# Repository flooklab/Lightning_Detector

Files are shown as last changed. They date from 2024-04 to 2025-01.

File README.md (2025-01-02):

# Lightning Detector

Lightning Detector is an experimental open hardware project for early notification about approaching thunderstorm activity.
It is a battery-powered (1x or 2x `CR2032`) device with low power consumption in mind and is based on an Arduino Nano 33 BLE
as microcontroller unit (MCU) and the `AS3935` "Franklin Lightning Sensor" chip by AMS/ScioSense as main detector element.  

For license information please see the [License Information](#user-content-license-information) section at the bottom.  

**! ! ! ! ! WARNING ! ! ! ! !**  
  
**Do _NOT_ actually use Lightning Detector as a serious device to warn you about lightnings or thunderstorms!**  
It might be that lightnings will **NOT** be detected and that you will **NOT** be notified about present or
approaching thunderstorms. You have to assume that the device is inherently **UNSAFE** and does **NOT**
work properly. There is **NO** guarantee for the fitness for any particular purpose whatsoever.  
**UNDER NO CIRCUMSTANCES** should you trust the information provided (or not provided) by the device.
Lightning Detector might **NOT** be tested thoroughly enough and is **NOT** even *intended* to be a reliable detector device.  
Note that being in a thunderstorm (especially without sufficient protection around you (such as a building))
is a very dangerous situation as you might suddenly be struck by lightning, which is potentially **LIFE-THREATENING**.
Generally, you should always try to combine multiple sources of information to assess the current risk of thunderstorms
and lightning strikes. Check the weather forecast and watch the sky. Dark clouds can be an early indicator.
If in doubt (or when there is/are audible thunder or visible lightnings at the latest), please seek shelter!  
  
**! ! ! ! ! WARNING ! ! ! ! !**  
  
See also below *DISCLAIMER AND LIABILITY* [*- OHL-W*](#user-content-disclaimer-and-liability---ohl-w) and
[*- GPL*](#user-content-disclaimer-and-liability---gpl) and [*- OFL*](#user-content-disclaimer-and-liability---ofl)!  
  
The `AS3935` detects lightning strikes indirectly by means of their accompanying electromagnetic radiation,
which is claimed to work up to a maximum distance of 40 kilometers according to its datasheet. For every
lightning that is detected by the `AS3935` the Lightning Detector is going to generate an acoustic notification
(buzzer beep). Additionally, information such as accumulated lightning count and estimated "thunderstorm distance"
etcetera may be shown on a connected display. You may also establish a serial connection via the Arduino USB
connector to read debug information such as detailed data for every lightning and battery voltage etcetera.
A number of internal settings of the `AS3935` can be configured/tweaked via DIP switches in order
to individually optimize detection efficiency and false positive rejection. For a more detailed
overview about the usable features of Lightning Detector please refer to the below sections
[Configuration / Modification](#user-content-configuration--modification) and [Usage](#user-content-usage).  

This project consists of two main components:

1. Hardware design files for a printed circuit board (PCB)
2. Firmware source code for the Arduino MCU

To assemble and use the Lightning Detector the following additional *active* components are required:

## Additional Components

- Arduino Nano 33 BLE (Rev1):  
  See for instance [here](https://store.arduino.cc/products/arduino-nano-33-ble).

- SparkFun Lightning Detector AS3935 (or an equivalent unit containing an AMS/ScioSense `AS3935` chip and appropriate antenna):  
  See for instance [here](https://www.sparkfun.com/products/15441).

- Waveshare 1.54inch e-Paper Display [**optional**, display usage can be configured/disabled, see [below](#user-content-configuration--modification)]:  
  See for instance [here](https://www.waveshare.com/product/1.54inch-e-paper-module.htm).

- SparkFun 16 I/O Expander Breakout SX1509 (or an equivalent unit containing a Semtech `SX1509` chip) [**optional**, required if the above display is used]:  
  See for instance [here](https://www.sparkfun.com/products/13601).

## Hardware Assembly

You should be able to make or order a Lightning Detector PCB using the contents of the [`Hardware/`](Hardware/) directory.
In particular, there are KiCad and also Gerber files, which should enable you to do this.  

To assemble the PCB you should use the parts listed in the bill of materials (BOM) in [`Hardware/BOM/`](Hardware/BOM/).
In [`Hardware/Render_Images/`](Hardware/Render_Images/) there are render images that can be used as a reference for assembly.  

Notes about direct soldering of the Arduino:

- The Arduino is soldered directly to the PCB, unlike the other active components listed in the above
  [Additional Components](#user-content-additional-components) section, which will be later connected via the pin headers on the bottom
  side of the PCB. You could also install pin sockets in place of the Arduino footprint to be able to easily remove/replace the Arduino.
- Components `J1`, `J7` and `R3` must be installed *before* `A1` (the Arduino), unless you choose the pin socket variant mentioned above.
- For reasons of power saving (due to the small coin cell capacity) you should **cut the "3v3" jumper** `SJ4` on the Arduino board.
  This is, of course, also only possible *before* installing the Arduino to the Lightning Detector PCB, so keep this in mind!
  Again, if you choose the pin socket variant for the Arduino, this can be fixed later. Note that with the cut jumper the
  USB connector will not be able to provide power anymore, which is why you will then have to provide power over the
  Lightning Detector PCB before being able to program the Arduino or otherwise use the USB serial connection.

Further notes:

- The bottom side pin headers `J1`, `J2` and `J7` must be soldered with a slight angle with respect to the
  PCB to leave enough space for jumper cables to be connected without interfering with other components' pins.
  It is particularly helpful to limit the length of the Arduino pin ends sticking through to the
  bottom side by deliberately soldering the Arduino at an increased distance to the board.
- The two pin headers `J2` and `J7` (for `I2C`) are meant for powering and controlling the display. If you decide to use
  Lightning Detector without a display (see [Firmware Building](#user-content-firmware-building) below), they can be left out.

### Connecting Periphery

Connecting the "periphery" modules can be simply done via jumper cables.  

The SparkFun AS3935 module must be connected to pin header `J1`. Its pins map to the module pins as follows:  
(`PWR` -> `3V3`), (`SCK` -> `SCK`), (`GND` -> `GND`), (`IRQ` -> `INT`), (`MISO` -> `MISO`), (`MOSI` -> `MOSI`), (`SEL` -> `CS`)  

For reasons of power saving you should disable the power LED on the SparkFun AS3935 module by **cutting the "LED" jumper** `JP5` there.  

If the pre-defined display configuration (i.e. Waveshare 1.54inch e-Paper Display + SparkFun 16 I/O Expander Breakout SX1509)
is going to be used, you can proceed as follows:

- Pin headers `J2` and `J7` should be connected to the power and `I2C` pins of the SparkFun SX1509 module, respectively:  
  (`PWR` -> `3V3`), (`GND` -> `GND`), (`SCL` -> `SCL`), (`SDA` -> `SDA`)
- The I/O pins `#12` through `#15` of the SX1509 module are connected to the e-Paper module like this:  
  (`#12` -> `BUSY`), (`#13` -> `RST`), (`#14` -> `DC`), (`#15` -> `CS`)
- Power pins of the e-Paper module (`VCC` and `GND`) may either be connected to `J2` as well
  (using split jumper cables) or simply to the spare `3V3` and `GND` pins on the SX1509 module.
- The e-Paper module shares the SPI bus with the AS3935 module. Hence two specific pins of `J1`
  must also be connected to the corresponding e-Paper module pins (using split jumper cables):  
  (`SCK` -> `CLK`), (`MOSI` -> `DIN`)

### Example Setup

The final assembly may look similar to this:  

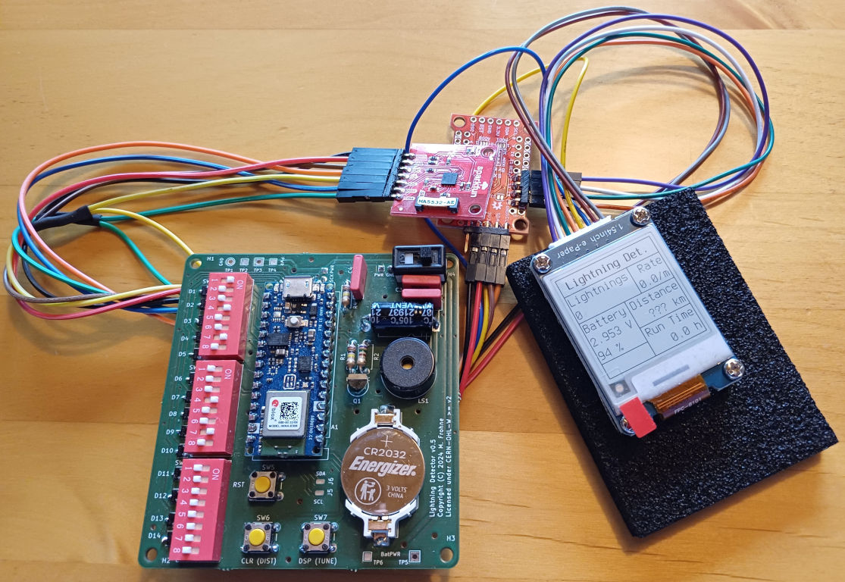
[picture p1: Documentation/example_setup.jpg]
Example setup


#### Case

In [`Hardware/Case/`](Hardware/Case/) there are CAD files for a 3D-printable case that can be
used if all above-mentioned additional periphery modules are attached to the back of the PCB
in a particular layout using the mounting holes and appropriate spacers, as can be seen below:  

<p align="center"><table><tr>
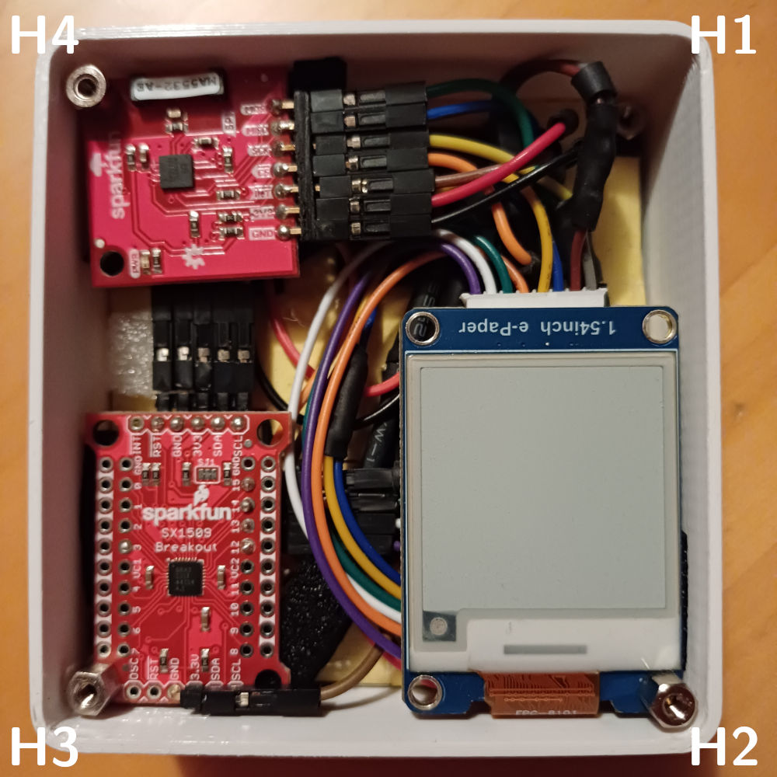
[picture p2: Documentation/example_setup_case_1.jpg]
<td width="33%"></td>
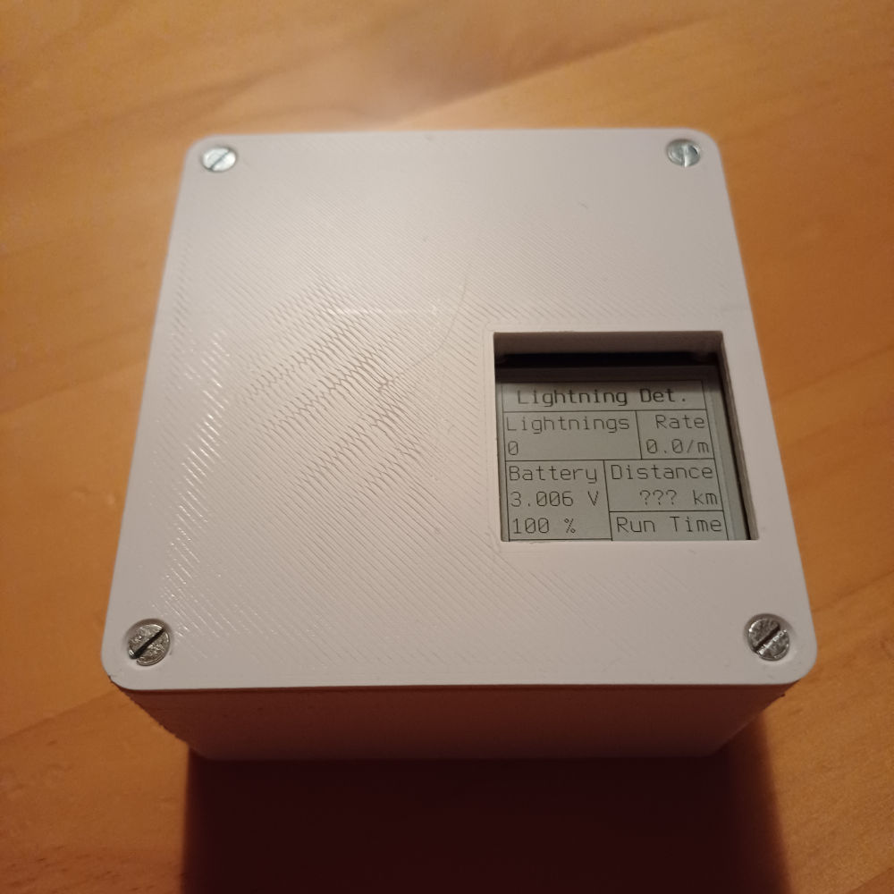
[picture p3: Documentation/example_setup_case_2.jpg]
<td width="33%"></td>
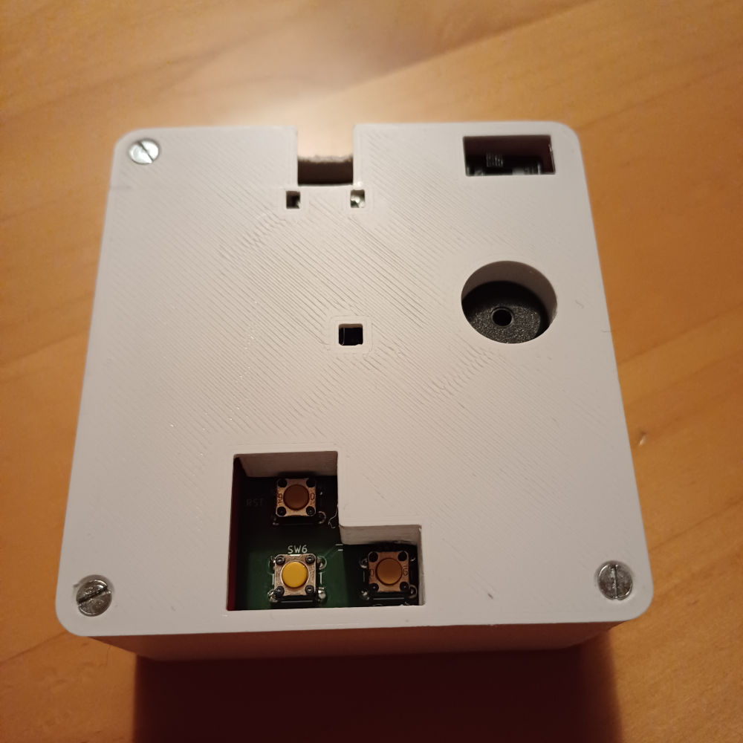
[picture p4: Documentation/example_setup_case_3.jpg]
<td width="33%"></td>
</tr></table></p>

Note that in this configuration the `AS3935` is very close to the rest of the electronics,
which had caused frequent false positive lightning interrupts in my case. This was successfully
suppressed by inserting a grounded sheet of copper foil between the PCB and the attached periphery.

## Firmware Building

Building and uploading the firmware can be accomplished with the [Arduino IDE](https://www.arduino.cc/en/software)
(tested with [Arduino IDE 1.x](https://github.com/arduino/arduino), but should also work with [Arduino IDE 2.x](https://github.com/arduino/arduino-ide)):

- Open the Sketch [`Firmware/lightning_detector/lightning_detector.ino`](Firmware/lightning_detector/lightning_detector.ino)
- If required, make code adjustments to configure things like presence of a display etcetera (see [below](#user-content-configuration--modification))
- Make sure to select the correct board type ("Arduino Nano 33 BLE")
- Connect the Arduino via USB and, if `SJ4` was cut (see [Hardware Assembly](#user-content-hardware-assembly) above), power up the Lightning Detector device
- Compile the sketch and then upload it to the Arduino

Depending on your operating system, your Arduino IDE version and your preference, you might have to make sure
that you additionally have the following software components installed, prior to building the firmware:

- The [Arduino Core for `mbed` MCUs](https://github.com/arduino/ArduinoCore-mbed) (including the [Arduino Core API](https://github.com/arduino/ArduinoCore-api))
- A working [GCC](https://gcc.gnu.org/) toolchain for the `arm-none-eabi` target platform (including [Newlib](https://www.sourceware.org/newlib/))
- A patched version of [BOSSA](https://github.com/arduino/BOSSA/commit/37600d1635f830cc0cdf7c56e586a021272c4e35) from Arduino for uploading the Sketch

Those can be either installed using the Arduino IDE board manager (simply look for "Mbed OS Nano Boards" and/or "Arduino Nano 33 BLE"),
or by yourself using existing packages provided by your operating system distribution or directly from the mentioned sources.

### Configuration / Modification

Before building the firmware you may want to do some code modifications, the most important/interesting of which are listed in the following:

- **Use different SX1509 I/O pins:**  
  If desired, the specific I/O pin numbers of the `SX1509` that are used for the e-Paper module signals `BUSY`, `RST`, `DC` and `CS`
  may be changed in the file [`pins.h`](Firmware/lightning_detector/pins.h) (within the `namespace SX1509Pins`).

- **Disable display usage:**  
  If no display is going to be connected, set the `USE_DISPLAY` macro in [`usedisplay.h`](Firmware/lightning_detector/usedisplay.h) to `USE_DISPLAY_NONE`.

- **Use a different display:**  
  The display part of the firmware is somewhat modular so that it is basically possible to use a completely different display module
  by "simply" writing a dedicated driver class implementation for it, which can of course be modified from the existing display driver
  (see [`display_waveshareepaper154bw_sx1509ioexpander.h`](Firmware/lightning_detector/display_waveshareepaper154bw_sx1509ioexpander.h)
  and [`display_waveshareepaper154bw_sx1509ioexpander.cpp`](Firmware/lightning_detector/display_waveshareepaper154bw_sx1509ioexpander.cpp)).  
  Furthermore, you will need to make the following changes:
  - Add a new macro to [`usedisplay.h`](Firmware/lightning_detector/usedisplay.h) and assign it to `USE_DISPLAY` there.
  - Add the new class header to [`display.h`](Firmware/lightning_detector/display.h) using the previously added macro.
  - Add a matching display declaration in the main [`lightning_detector.ino`](Firmware/lightning_detector/lightning_detector.ino) file (search for `USE_DISPLAY`).

- **General tweaks:**  
  At the top of [`lightning_detector.ino`](Firmware/lightning_detector/lightning_detector.ino), right before the declaration of
  the *interrupt flags*, there are a bunch of constant definitions, which can be adjusted to your liking, such as, for instance:
  - `buzzerFreq`: Buzzer beep frequency
  - `buzzerLightBeepSecs`: Buzzer beep duration for lightning notification
  - `lightRateAvrgMins`: Minimum averaging time to determine current lightning rate
  - `systemMinVoltage`: Largest minimum allowed operating voltage for any system component
  - `systemMaxCurrent`: Maximum system current (e.g. during beep or display update)
  - `systemBatteryCount`: Number of installed coin cells

### Documentation

Firmware code documentation can be generated using [Doxygen](https://github.com/doxygen/doxygen)
(there is a `Doxyfile` in [`Documentation/Firmware/`](Documentation/Firmware/)).

## Usage

### Before Use

- **DIP switch settings:**  

  Make sure to set the DIP switches to the default configuration before use. From left to right (`D1` to `D14`) this is:

  ```
  Register AFE_GB NF_LEV WDTH SREJ TUN_CAP LCO_FDIV MIN_NUM_LIGH
  Value    10010  010    0010 0010 0000    00       00
  ```

  **Note 1:** The default amplifier gain setting `AFE_GB` is recommended for _indoor_ use. For _outdoor_ use they recommend `01110` instead.  
  **Note 2:** The _optimal_ "default" `TUN_CAP` setting is later determined via the antenna tuning procedure (see below).
              The above default is just an arbitrary starting point.  

  The register settings can of course be tweaked as you like. For the meaning/effect of each register please refer to the `AS3935` datasheet.  

- **Antenna tuning:**  

  The AS3935 module antenna needs to be tuned to the resonance frequency of `500 kHz +- 17.5 kHz` before use.
  This can be achieved with the antenna tuning mode (see below).

### Using The Lightning Detector

There are three different "run modes" that can be selected at startup:
- _Normal_: Normal lightning detection mode
- _UnmaskDisturbers_: Same as _Normal_ mode, except for unmasked disturber interrupts and enabled serial connection
- _TuneAntenna_: Antenna tuning mode

The default mode is the _Normal_ mode. Just power up the device to use this mode.  

The _Normal_ mode can be overridden at startup by pressing the `CLR (DIST)` button (_UnmaskDisturbers_) or the `DSP (TUNE)` button (_TuneAntenna_) when/until
the second short buzzer beep is played. There is a first short buzzer beep followed by a `500 ms` delay that enables you to press the buttons in time.

- **_Normal_:**  

  In the _Normal_ mode the main functionality is the lightning notification. Whenever the `AS3935` detects a lightning signal the
  Arduino wakes up from sleep mode (which is used most of the time) via interrupt request and then there is going to be a buzzer
  beep and a short _red_ blip of the RGB LED on the Arduino board. After that the Arduino goes to sleep mode again to save power.  

  Other wake-up reasons (i.e. available functionality) are one of the two push buttons (`CLR (DIST)` or `DSP (TUNE)`) being pressed,
  other `AS3935` IRQ events and a recurring timer timeout (see explanations below). All of the `AS3935` interrupts produce a
  _red_ RGB LED blip, pressed buttons produce a _green_ RGB LED blip and the timer wake-up produces a _blue_ RGB LED blip.  

  Using the lightning interrupts the total number of lightnings is counted and an average lightning rate is calculated.
  Also the estimated storm distance is read for every lightning interrupt and for the dedicated "distance changed" interrupts
  (purely age-based statistics evolution). All of this information (and more) can be displayed on the display on request
  (see below), including, which was the last `AS3935` interrupt. Note, in that regard, that there is also an interrupt
  for too much antenna/amplifier noise. This does not have any direct effect other than the LED blips but can thus
  of course be checked for on the display. Note that the _disturber_ signal interrupts are disabled in this mode.  

  The timer wake-up is used (a) to periodically monitor the battery voltage and (b) to avoid being locked when an `AS3935`
  interrupt is raised while going to sleep as the IRQ signal is not transient but stays high until the interrupt type
  is read. The timer itself is also used to calculate the lightning rate and to accumulate the device's run time.  

  Pressing the `CLR (DIST)` button clears the `AS3935` distance estimation statistics, resets lightning counter
  and lightning rate as well as the latest interrupt type and the latest read lightning "energy" value.  

  Pressing the `DSP (TUNE)` button updates the display. The displayed information is (~ from top-left to bottom-right):
    1. Lightning count
    2. Current lightning rate
    3. Battery state (raw voltage and an estimated charge percentage)
    4. Estimated storm distance from `AS3935` ("???" if reported out of range)
    5. Short status information (from left to right):
        - 'D' if run mode is _UnmaskDisturbers_ (see dedicated section), just ' ' (space) else
        - 'S' if serial connection is enabled (see _UnmaskDisturbers_ mode as well), just ' ' (space) else
        - Latest interrupt type:
          - "" (nothing) for "lightning"
          - "dDst" for "distance changed"
          - "Dist" for "disturber detected" (see _UnmaskDisturbers_ mode)
          - "NOIS" for "too much noise"
          - "INV" for invalid interrupts
    6. Approximate device run time as hours (`xx.x h`) if below 24 hours or as days+hours (`xxxd xxh`) otherwise.

  Note that the reported battery percentage is just an estimate using a look-up table based on some discharge curve. This is already
  inaccurate, although it does take current consumption and internal battery resistance into account. However, those two quantities
  are just approximately known in advance and also the `CR2032` batteries do seem to have somewhat unpredictable, additional voltage
  fluctuations under varying load currents. Therefore please consider the percentage value just as a **very** rough estimate.
  The value seems to get more predictable/reliable, though, when the device has been continuously running for a few days.  

  Also note that the reported "storm distance" value should not necessarily be trusted. This quantity cannot really be _measured_
  using a single sensor at just one place. The value comes directly out of the `AS3935` chip and the datasheet claims that the chip
  can estimate the storm distance by means of a statistical algorithm. There is little explanation of this algorithm, so it might
  actually work but it might as well not work satisfactorily. The value is in any case shown on the display for completeness.  

  If you see the noise interrupt and cannot get rid of it via the `CLR (DIST)` button, refer to the `AS3935` datasheet for how to change the
  register settings to mitigate the noise issue. Note that the configuration is only read from the DIP switches _once_ at startup/reset.  

  The maximum run time of the device is mostly limited by the `AS3935` current consumption. This _should_ be around `350 µA` _or_ `60 µA` for the
  "signal verification mode" _or_ the "listening mode", respectively, according to the datasheet. The sensor should automatically switch to the
  power saving "listening mode" when there is no significant antenna activity, but so far I _could not confirm this by measurements_. Note that
  I made the measurements in a populated area (i.e. picked up noise from surrounding electronics etcetera) and that it might eventually switch
  to "listening mode" when in the back country (which I did _not_ test, though). Adding the much smaller Arduino sleep current (and accounting
  for a higher current during the occasional wake-ups), this means that the Lightning Detector should be able to run for either _almost 6 weeks_
  ("signal verification mode") or _up to 5 months_ ("listening mode") when using two good, parallel `CR2032` batteries (not tested yet either).
  Note, of course, that the achievable run time will be much smaller if you mostly or only use the device during known thunderstorms.  

  The operating voltage is measured approximately every 30 minutes (or every 10 minutes when there is high lightning activity, due to the increased
  current consumption). This only happens when the Arduino wakes up anyway because of one of the mentioned interrupts. If the voltage dropped below
  the point where the minimum operating voltage could not be sustained under the maximum expected current consumption (i.e. below around `2.51 V`),
  then the display is automatically updated one last time and both the buzzer beep and updating the display get disabled to save power. This is also
  acoustically notified using a few seconds long beep sequence (12 beeps). The battery percentage on the display should now read (approximately)
  `0 %`. What remains for the lightning notification are the mentioned RGB LED blips (and serial debug messages for _UnmaskDisturbers_ mode,
  see section below). When the voltage finally drops below the minimum voltage for the `AS3935` chip (`2.4 V`), then the device becomes useless.
  As it cannot switch itself off, it now enters an infinite "sleep loop". This basically disables all functionality, except that now, whenever the
  previously mentioned wake-up timer times out, there will be a 5x blink sequence of the _blue_ RGB LED to remember to switch the device off.

- **_UnmaskDisturbers_:**  

  This mode basically works the same as the _Normal_ mode. The difference is that the `AS3935` now also generates interrupts
  for signals recognized as "disturbers" and that the serial connection will be enabled if a connection is attempted at startup.  

  The disturber interrupts do _not_ generate beeps but can still be recognized by the _red_ RGB LED blips.
  Furthermore it can now be seen on the display if the last `AS3935` interrupt was caused by a disturber.
  If the serial connection is active (see also below), the disturber event is also printed to the serial console.  

  After the second short buzzer beep at startup, if _UnmaskDisturbers_ mode was selected, there is a delay of 5 seconds during which you can attempt
  to connect to the Arduino via a serial console (`9600 Baud`). If this is successful, this will be be used in the following to output a number
  of debug messages, such as `AS3935` events, measured `VDD` voltage etcetera. Please refer to the code for all the possible messages.

- **_TuneAntenna_:**  

  This mode starts with a "buzzer response" test sequence, which can be ignored for the first procedure (see below)
  but can be helpful for the second "acoustic matching" procedure and is hence further explained there (see further below).  

  Whenever the `DSP (TUNE)` button gets pressed the current DIP switch configuration is read and applied to the `AS3935`.
  This can be used to adjust the `TUN_CAP` register setting until the resonance frequency matches the `500 kHz` (remember
  the uncertainty window of `+- 3.5%`, respectively `+- 17.5 kHz`). There are two possibilities for the tuning procedure:

  - Tuning with an oscilloscope or similar devices:  
    Set `LCO_FDIV` to `00` or an appropriate higher value given the bandwidth limit of your measurement device.
    The `00` setting yields a digital `~ 500/16 kHz = 31.25 kHz` signal at the IRQ pin of the AS3935 module,
    which can then be measured and matched using the `TUN_CAP` register. `LCO_FDIV` equal to `01` divides
    by 32, `10` divides by 64 and `11` divides by 128 (`~ 3.9 kHz`).

  - Tuning using the buzzer and acoustic frequency matching:  
    If no such measurement device is available, set `LCO_FDIV` to `11` (or `10`). This will reproduce the digital
    resonance signal of the IRQ pin on the buzzer output such that you can acoustically match the audible frequency
    to `~ 500/128 kHz` (or `~ 500/64 kHz`) using an instrument tuner or by generating a beat signal versus the target
    frequency. The sound always plays as long as the `DSP (TUNE)` button is being pressed. Note that you should
    listen to the "buzzer response" test sequence played in the beginning to assess the suitability of the used
    buzzer for the acoustic matching procedure. Depending on the buzzer model (avoid its resonance frequency)
    and the chosen frequency (`LCO_FDIV`) you might not be able to resolve different frequencies sufficiently
    well to be able to properly tune the antenna. The sequence plays 13 beeps with frequencies around the
    divided target frequency, all separated by steps of 10 cents. You should be able to resolve at least
    around 3 of those 13 frequencies. The test uses the frequency according to the `LCO_FDIV`
    setting at startup. Start with `11` and if that does not work out use `10` instead.

## Known Issues

- Sometimes the Arduino appears to take rather long to wake up from sleep mode. When you wake it up by pressing
  one of the push buttons, this _can_ result in it getting stuck due to the debouncing (recognizable by the
  _green_ RGB LED being continuously on). You just need to press the button again to resolve this.
- Apparently, as already mentioned in the [Case](#user-content-case) section, the `AS3935`
  raises false positive lightning interrupts when it gets too close to the main PCB.
  Hence you might need to add additional shielding, depending on your setup.

## License Information

Copyright (C) 2024–2025 M. Frohne  

Lightning Detector is licensed under the "*CERN Open Hardware Licence, Version 2 - Weakly Reciprocal*" or (at your option) any later version.  
(please refer to the file [`LICENSE.OHL-W`](LICENSE.OHL-W))  

This does NOT apply to the firmware code that is found in the [`Firmware/`](Firmware/) directory, which is instead
licensed under the "*GNU General Public License, Version 3*" or (at your option) any later version.  
(please refer to the file [`LICENSE.GPL`](LICENSE.GPL))  

Note also that the firmware files in the directory [`Firmware/lightning_detector/fonts/`](Firmware/lightning_detector/fonts/) embed a subset
of the Terminus Font and are hence additionally licensed under the "*SIL Open Font License, Version 1.1*", with Reserved Font Name "Terminus Font".  
(please refer to the file [`LICENSE.OFL`](LICENSE.OFL))

### DISCLAIMER AND LIABILITY - OHL-W

- DISCLAIMER OF WARRANTY -- The Covered Source and any Products
  are provided 'as is' and any express or implied warranties,
  including, but not limited to, implied warranties of
  merchantability, of satisfactory quality, non-infringement of
  third party rights, and fitness for a particular purpose or use
  are disclaimed in respect of any Source or Product to the
  maximum extent permitted by law. The Licensor makes no
  representation that any Source or Product does not or will not
  infringe any patent, copyright, trade secret or other
  proprietary right. The entire risk as to the use, quality, and
  performance of any Source or Product shall be with You and not
  the Licensor. This disclaimer of warranty is an essential part
  of this Licence and a condition for the grant of any rights
  granted under this Licence.

- EXCLUSION AND LIMITATION OF LIABILITY -- The Licensor shall, to
  the maximum extent permitted by law, have no liability for
  direct, indirect, special, incidental, consequential, exemplary,
  punitive or other damages of any character including, without
  limitation, procurement of substitute goods or services, loss of
  use, data or profits, or business interruption, however caused
  and on any theory of contract, warranty, tort (including
  negligence), product liability or otherwise, arising in any way
  in relation to the Covered Source, modified Covered Source
  and/or the Making or Conveyance of a Product, even if advised of
  the possibility of such damages, and You shall hold the
  Licensor(s) free and harmless from any liability, costs,
  damages, fees and expenses, including claims by third parties,
  in relation to such use.

See the CERN Open Hardware Licence for more details. 

### DISCLAIMER AND LIABILITY - GPL

Lightning Detector's firmware is distributed in the hope that it
will be useful, but WITHOUT ANY WARRANTY; without even the implied
warranty of MERCHANTABILITY or FITNESS FOR A PARTICULAR PURPOSE.  

See the GNU General Public License for more details.

### DISCLAIMER AND LIABILITY - OFL

THE FONT SOFTWARE IS PROVIDED "AS IS", WITHOUT WARRANTY OF ANY KIND,
EXPRESS OR IMPLIED, INCLUDING BUT NOT LIMITED TO ANY WARRANTIES OF
MERCHANTABILITY, FITNESS FOR A PARTICULAR PURPOSE AND NONINFRINGEMENT
OF COPYRIGHT, PATENT, TRADEMARK, OR OTHER RIGHT. IN NO EVENT SHALL THE
COPYRIGHT HOLDER BE LIABLE FOR ANY CLAIM, DAMAGES OR OTHER LIABILITY,
INCLUDING ANY GENERAL, SPECIAL, INDIRECT, INCIDENTAL, OR CONSEQUENTIAL
DAMAGES, WHETHER IN AN ACTION OF CONTRACT, TORT OR OTHERWISE, ARISING
FROM, OUT OF THE USE OR INABILITY TO USE THE FONT SOFTWARE OR FROM
OTHER DEALINGS IN THE FONT SOFTWARE.  

See the SIL Open Font License for more details.

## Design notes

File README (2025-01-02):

Lightning Detector, an experimental open hardware project for early notification about approaching thunderstorm activity.
Copyright (C) 2024–2025 M. Frohne

Lightning Detector is licensed under the "CERN Open Hardware Licence, Version 2 - Weakly Reciprocal" or (at your option) any later version.
(please refer to the file 'LICENSE.OHL-W')

This does NOT apply to the firmware code that is found in the 'Firmware/' directory, which is instead
licensed under the "GNU General Public License, Version 3" or (at your option) any later version.
(please refer to the file 'LICENSE.GPL')

Note also that the firmware files in the directory 'Firmware/lightning_detector/fonts/' embed a subset of the Terminus Font
and are hence additionally licensed under the "SIL Open Font License, Version 1.1", with Reserved Font Name "Terminus Font".
(please refer to the file 'LICENSE.OFL')

###########################################################################################################################################

! ! ! ! ! WARNING ! ! ! ! !

Do NOT actually use Lightning Detector as a serious device to warn you about lightnings or thunderstorms!
It might be that lightnings will NOT be detected and that you will NOT be notified about present or
approaching thunderstorms. You have to assume that the device is inherently UNSAFE and does NOT
work properly. There is NO guarantee for the fitness for any particular purpose whatsoever.
UNDER NO CIRCUMSTANCES should you trust the information provided (or not provided) by the device.
Lightning Detector might NOT be tested thoroughly enough and is NOT even intended to be a reliable detector device.
Note that being in a thunderstorm (especially without sufficient protection around you (such as a building))
is a very dangerous situation as you might suddenly be struck by lightning, which is potentially LIFE-THREATENING.
Generally, you should always try to combine multiple sources of information to assess the current risk of thunderstorms
and lightning strikes. Check the weather forecast and watch the sky. Dark clouds can be an early indicator.
If in doubt (or when there is/are audible thunder or visible lightnings at the latest), please seek shelter!

! ! ! ! ! WARNING ! ! ! ! !

###########################################################################################################################################

For more information please see the file 'README.md'.

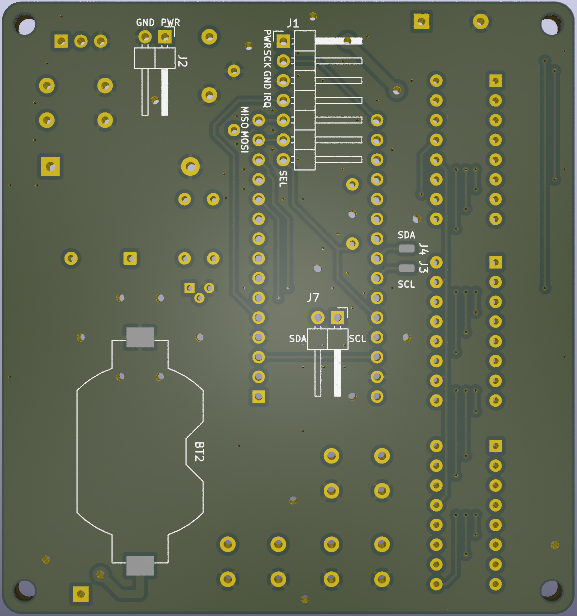
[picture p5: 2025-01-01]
Hardware/Render_Images/2_bare_pcb_back.png

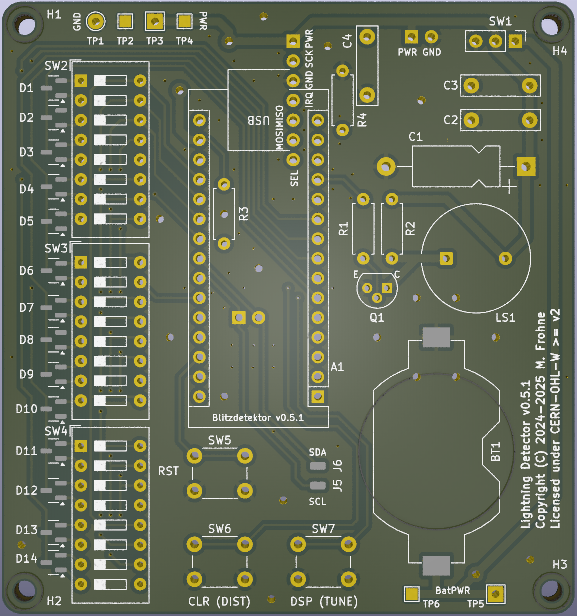
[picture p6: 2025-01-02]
Hardware/Render_Images/1_bare_pcb_front.png

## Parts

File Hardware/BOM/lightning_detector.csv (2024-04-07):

ID | Reference | Footprint | Quantity | Description | Value
1 | SW5,SW6,SW7 | SW_PUSH_6mm | 3 | SW_PUSH_6mm
2 | D1,D2,D3,D4,D5,D6,D7,D8,D9,D10,D11,D12,D13,D14 | SOT-23 | 14 | Schottky Diode Dual Common Anode
3 | SW2,SW3,SW4 | SW_DIP_SPSTx08_Slide_9.78x22.5mm_W7.62mm_P2.54mm | 3 | SW_DIP_SPSTx08_Slide_9.78x22.5mm_W7.62mm_P2.54mm
4 | C2,C3,C4 | C_Rect_L10.0mm_W2.5mm_P7.50mm_MKS4 | 3 | C_Rect_L10.0mm_W2.5mm_P7.50mm_MKS4 | 100n
5 | LS1 | Indicator_PUI_AI-1440-TWT-24V-2-R | 1 | Piezoelectric Buzzer, f_R ~ O(1 kHz)
6 | Q1 | TO-92 | 1 | BC547C
7 | R1,R3,R4 | R_Axial_DIN0207_L6.3mm_D2.5mm_P7.62mm_Horizontal | 3 | R_Axial_DIN0207_L6.3mm_D2.5mm_P7.62mm_Horizontal | 100k
8 | R2 | R_Axial_DIN0207_L6.3mm_D2.5mm_P7.62mm_Horizontal | 1 | R_Axial_DIN0207_L6.3mm_D2.5mm_P7.62mm_Horizontal | 750
9 | C1 | CP_Axial_L11.0mm_D5.0mm_P18.00mm_Horizontal | 1 | CP_Axial_L11.0mm_D5.0mm_P18.00mm_Horizontal | 220u
10 | SW1 | PinHeader_1x03_P2.54mm_Vertical | 1 | SW_SPDT_P2.54mm
11 | A1 | Arduino_Nano | 1 | Arduino Nano 33 BLE Rev1
12 | BT1,BT2 | BatteryHolder_Keystone_1058_1x2032 | 2 | BatteryHolder_Keystone_1058_1x2032
13 | J1 | PinHeader_1x07_P2.54mm_Horizontal | 1 | PinHeader_1x07_P2.54mm_Horizontal
14 | J2,J7 | PinHeader_1x02_P2.54mm_Horizontal | 2 | PinHeader_1x02_P2.54mm_Horizontal

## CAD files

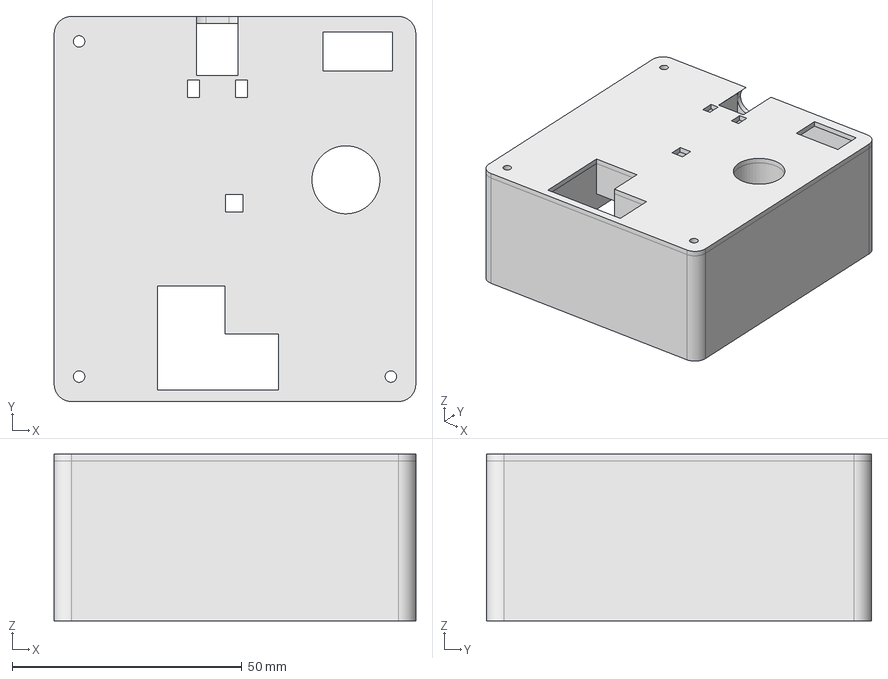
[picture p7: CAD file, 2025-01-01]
Hardware/Case/lightning_detector_case_top.step
78.7 x 83.7 x 36.3 mm

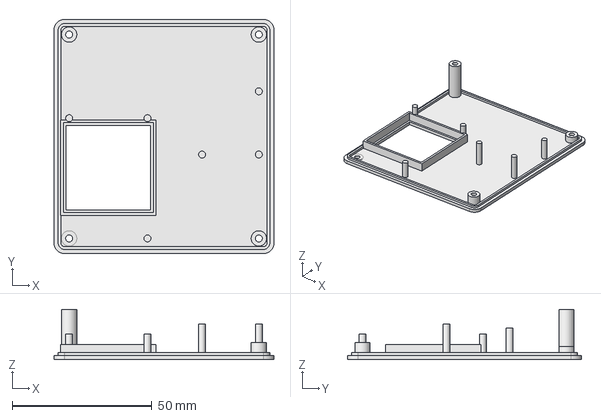
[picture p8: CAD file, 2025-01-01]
Hardware/Case/lightning_detector_case_bottom.step
78.7 x 83.7 x 17.9 mm

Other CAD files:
Hardware/Case/lightning_detector_case_bottom.stl
Hardware/Case/lightning_detector_case_top.stl

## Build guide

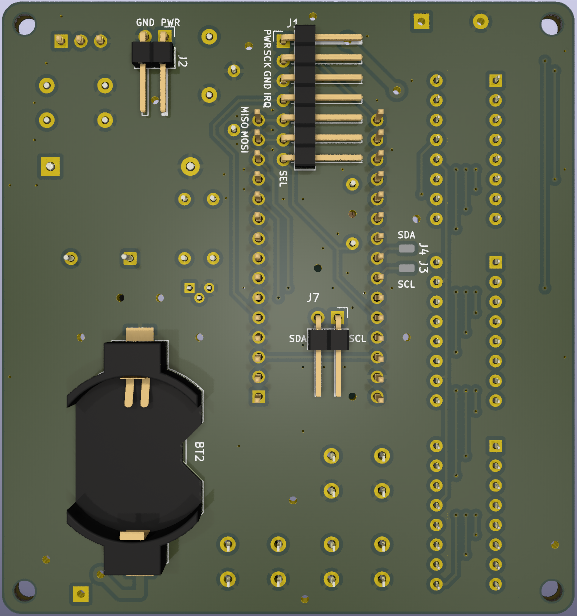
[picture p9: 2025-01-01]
Hardware/Render_Images/4_assembled_pcb_back.png

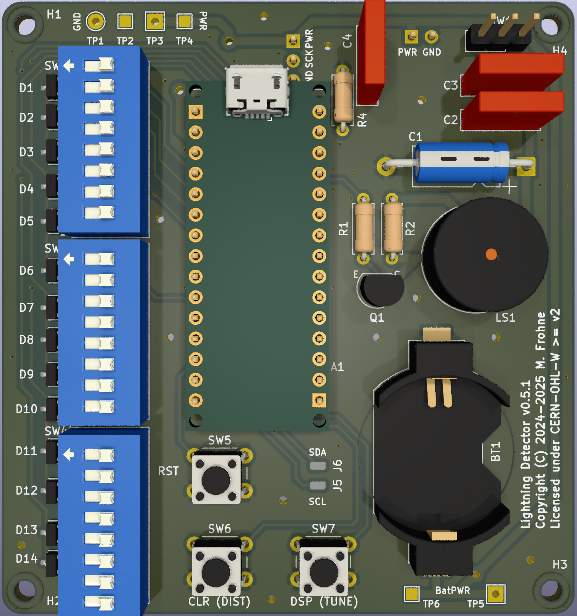
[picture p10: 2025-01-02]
Hardware/Render_Images/3_assembled_pcb_front.png

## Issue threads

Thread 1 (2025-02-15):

AS3935 Stroke integration threshold does not seem to work.

rpbgit, 2025-02-15:
Have 3935 running fine on SPI bus.  And most everything seems like its working well.

I am now tuning some parameters and it appears the Strike Theshold does not seem to work.

i have a lightning simulator that indeed generates lightning strokes as expected.  however, no matter what i set the strike threshold register bits to (values of 0x00-0x03), the first strike causes the interrupt request to be asserted to the micro.

i would have expected that the INTR line would be negated until the threshold count is exceeded.

Reading the INT source register (ISR) negates the INTR pin as expected. I am waiting 2ms from INTR recognition to reading of the ISR as spec mandates.  is clearing of the integration stats require in the ISR?   manually doing a clear statistics does not change the bahavior.

i have the Disturber mask set to prevent INTR from that source and the noise floor is set so that no noise events are generated.   Yet still, the first strike created by my strike generator board results in the INTR pin being asserted.

why is this not working ?   have i mis-interpreted the spec documents?

flooklab, 2025-03-04:
Hi, I cannot really help you with this. If you are talking about the `MIN_NUM_LIGH` register, maybe your "lightning simulator" is just too simple and does not generate a proper signature for a single lightning, maybe there's an error in your register writing, could be a lot of things...

I am closing this issue anyway because it does not seem to refer to this particular project.

Closed 2025-03-04.

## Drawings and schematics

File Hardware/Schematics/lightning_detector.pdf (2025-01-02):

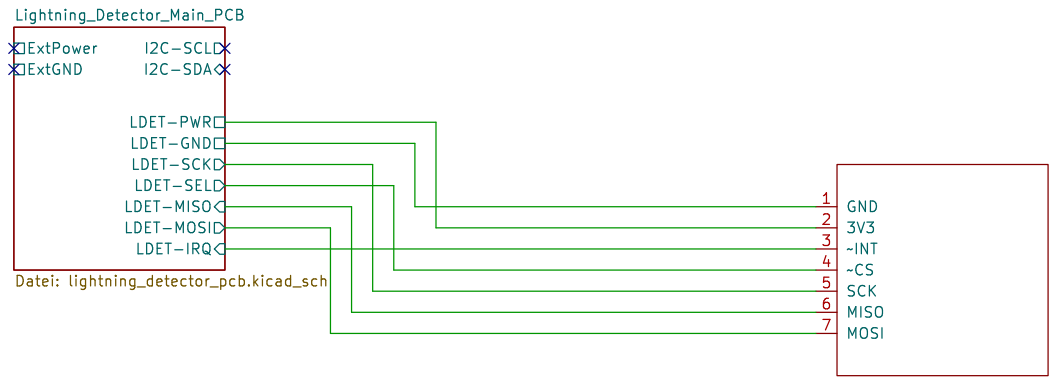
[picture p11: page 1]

LDET-PWR
LDET-GND
LDET-SCK
LDET-SEL
LDET-MISO
LDET-MOSI LDET-IRQ

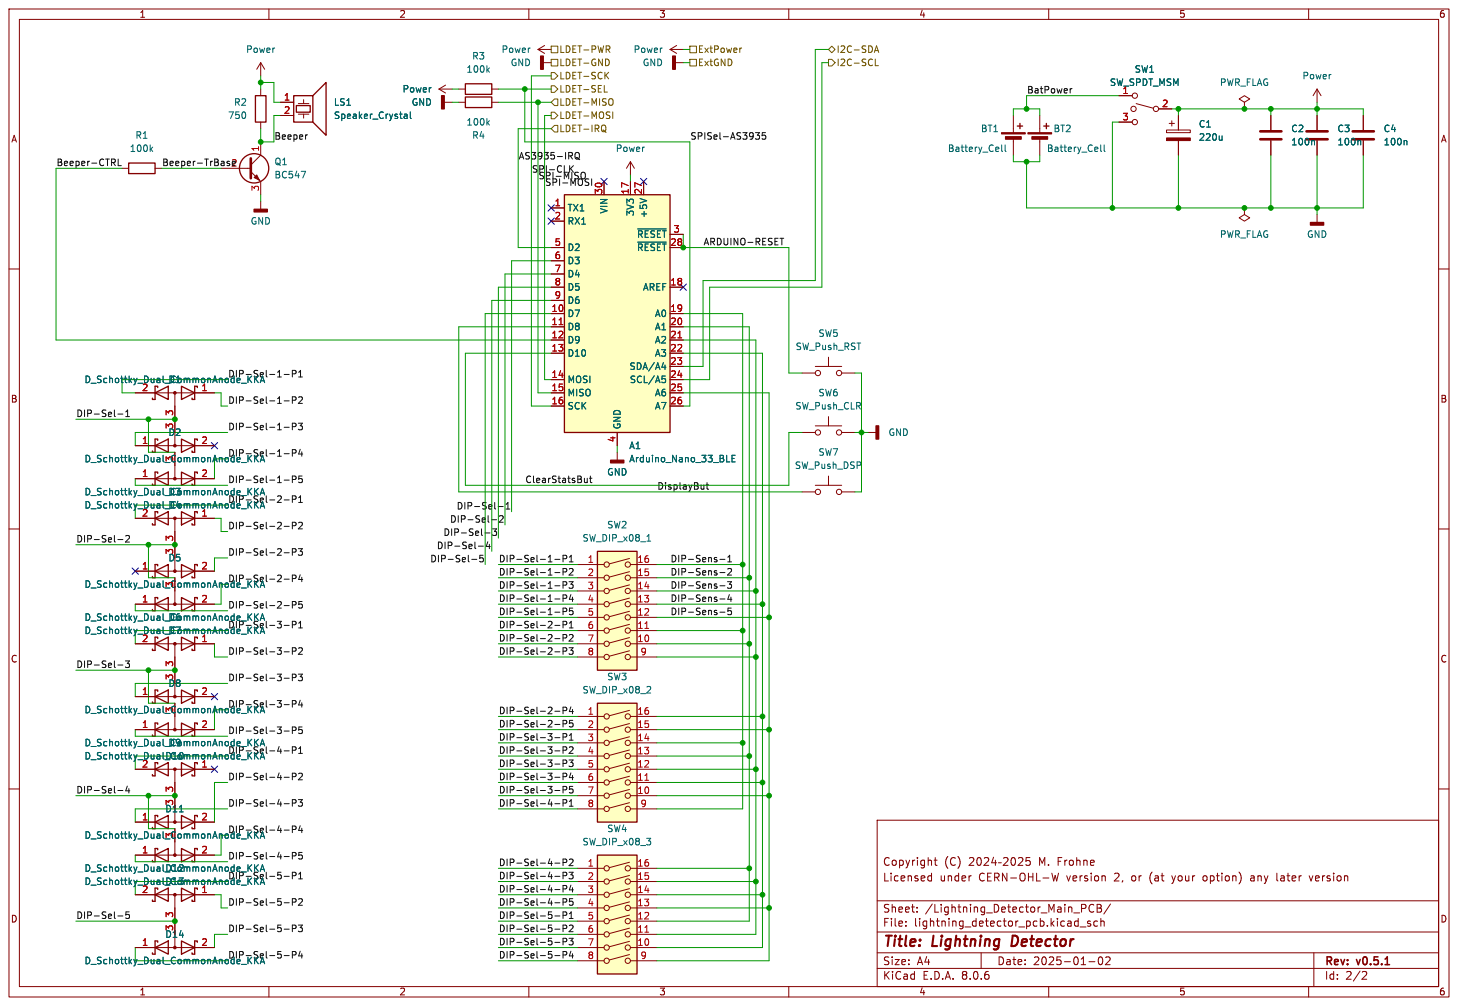
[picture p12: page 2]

3 GND
DIP-Sel-2 DIP-Sel-5

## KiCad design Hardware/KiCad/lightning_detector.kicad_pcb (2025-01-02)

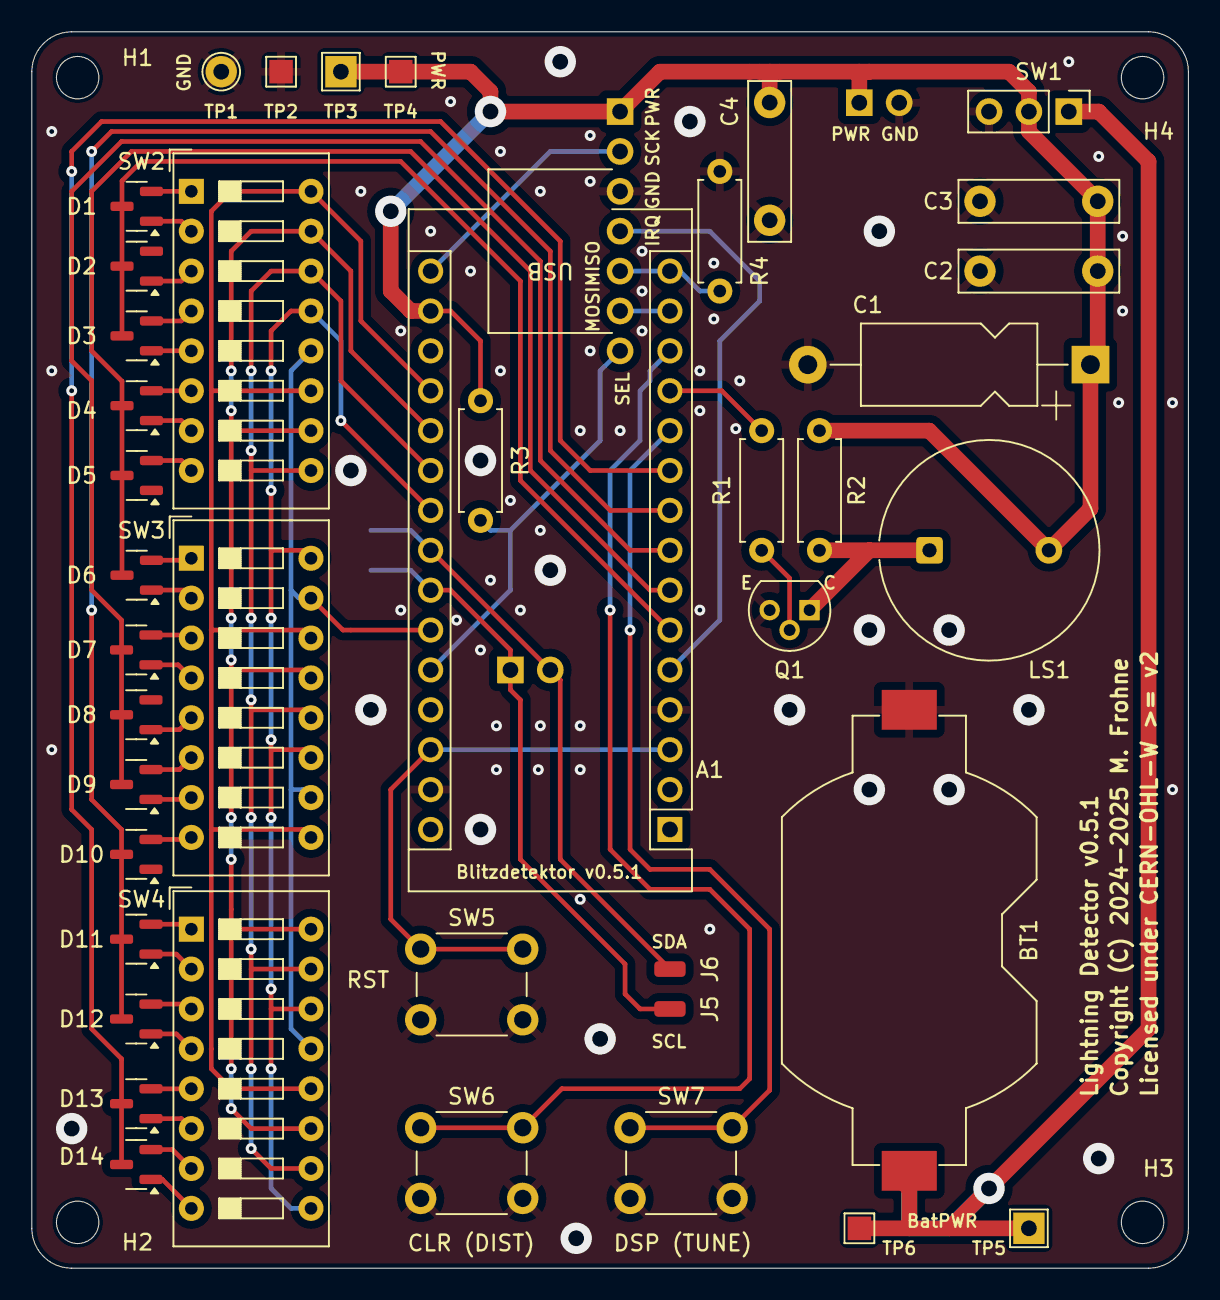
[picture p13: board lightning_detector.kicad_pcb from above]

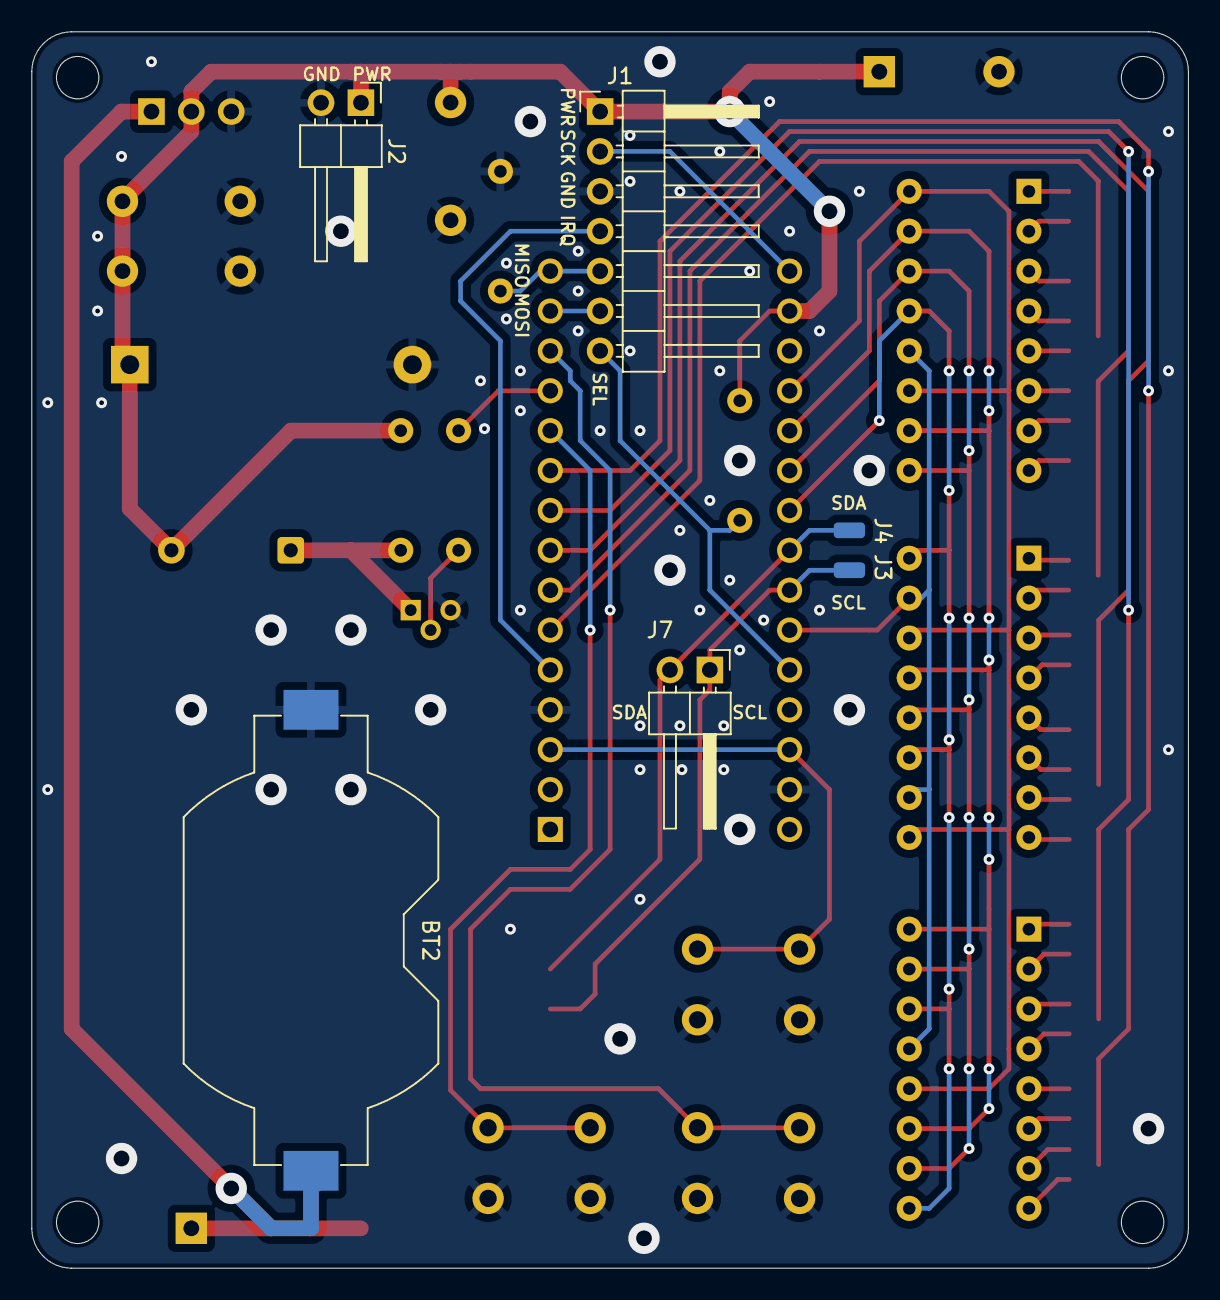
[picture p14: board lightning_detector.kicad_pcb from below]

Board: 2 copper layers, 73.7 x 78.7 mm, 51 parts (6 on the bottom side), 50 nets.

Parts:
A1: Arduino_Nano
BT1, BT2: BatteryHolder_Keystone_1058_1x2032
C1: CP_Axial_L11.0mm_D5.0mm_P18.00mm_Horizontal
C2, C3, C4: C_Rect_L10.0mm_W2.5mm_P7.50mm_MKS4
D1, D2, D3, D4, D5, D6, D7, D8, D9, D10, D11, D12, D13, D14: SOT-23
H1, H2, H3, H4: MountingHole_2.7mm_M2.5_DIN965
J1: PinHeader_1x07_P2.54mm_Horizontal
J2, J7: PinHeader_1x02_P2.54mm_Horizontal
J3, J4, J5, J6: SolderWirePad_1x01_SMD_1x2mm
LS1: Indicator_PUI_AI-1440-TWT-24V-2-R
Q1: TO-92
R1, R2, R3, R4: R_Axial_DIN0207_L6.3mm_D2.5mm_P7.62mm_Horizontal
SW1: PinHeader_1x03_P2.54mm_Vertical
SW2, SW3, SW4: SW_DIP_SPSTx08_Slide_9.78x22.5mm_W7.62mm_P2.54mm
SW5, SW6, SW7: SW_PUSH_6mm
TP1: TestPoint_THTPad_D2.0mm_Drill1.0mm
TP2, TP4, TP6: TestPoint_Pad_1.5x1.5mm
TP3, TP5: TestPoint_THTPad_2.0x2.0mm_Drill1.0mm

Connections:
ARDUINO-RESET: A1.3, A1.28, SW5.1
AS3935-IRQ: A1.5, J1.4
BatPower: BT1.1, BT2.1, SW1.1, TP5.1, TP6.1
Beeper: LS1.1, Q1.1, R2.2
Beeper-CTRL: A1.12, R1.1
Beeper-TrBase: Q1.2, R1.2
ClearStatsBut: A1.13, SW6.1
DIP-Sel-1: A1.6, D1.3, D2.3, D3.3
DIP-Sel-1-P1: D1.2, SW2.1
DIP-Sel-1-P2: D1.1, SW2.2
DIP-Sel-1-P3: D2.1, SW2.3
DIP-Sel-1-P4: D3.2, SW2.4
DIP-Sel-1-P5: D3.1, SW2.5
DIP-Sel-2: A1.7, D4.3, D5.3, D6.3
DIP-Sel-2-P1: D4.2, SW2.6
DIP-Sel-2-P2: D4.1, SW2.7
DIP-Sel-2-P3: D5.2, SW2.8
DIP-Sel-2-P4: D6.2, SW3.1
DIP-Sel-2-P5: D6.1, SW3.2
DIP-Sel-3: A1.8, D7.3, D8.3, D9.3
DIP-Sel-3-P1: D7.2, SW3.3
DIP-Sel-3-P2: D7.1, SW3.4
DIP-Sel-3-P3: D8.1, SW3.5
DIP-Sel-3-P4: D9.2, SW3.6
DIP-Sel-3-P5: D9.1, SW3.7
DIP-Sel-4: A1.9, D10.3, D11.3, D12.3
DIP-Sel-4-P1: D10.2, SW3.8
DIP-Sel-4-P2: D11.2, SW4.1
DIP-Sel-4-P3: D11.1, SW4.2
DIP-Sel-4-P4: D12.2, SW4.3
DIP-Sel-4-P5: D12.1, SW4.4
DIP-Sel-5: A1.10, D13.3, D14.3
DIP-Sel-5-P1: D13.2, SW4.5
DIP-Sel-5-P2: D13.1, SW4.6
DIP-Sel-5-P3: D14.2, SW4.7
DIP-Sel-5-P4: D14.1, SW4.8
DIP-Sens-1: A1.19, SW2.11, SW2.16, SW3.9, SW3.14, SW4.12
DIP-Sens-2: A1.20, SW2.10, SW2.15, SW3.13, SW4.11, SW4.16
DIP-Sens-3: A1.21, SW2.9, SW2.14, SW3.12, SW4.10, SW4.15
DIP-Sens-4: A1.22, SW2.13, SW3.11, SW3.16, SW4.9, SW4.14
DIP-Sens-5: A1.25, SW2.12, SW3.10, SW3.15, SW4.13
DisplayBut: A1.11, SW7.1
GND: A1.4, A1.29, BT1.2, BT2.2, C1.2, C2.1, C3.1, C4.1, J1.3, J2.2, Q1.3, R4.2, SW1.3, SW5.2, SW6.2, SW7.2, TP1.1, TP2.1
I2C-SCL: A1.24, J3.1, J5.1, J7.1
I2C-SDA: A1.23, J4.1, J6.1, J7.2
Power: A1.17, C1.1, C2.2, C3.2, C4.2, J1.1, J2.1, LS1.2, R2.1, R3.2, SW1.2, TP3.1, TP4.1
SPI-CLK: A1.16, J1.2
SPI-MISO: A1.15, J1.5, R4.1
SPI-MOSI: A1.14, J1.6
SPISel-AS3935: A1.26, J1.7, R3.1

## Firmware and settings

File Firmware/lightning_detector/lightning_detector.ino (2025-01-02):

/*
////////////////////////////////////////////////////////////////////////////////////
//
//  This file is part of the firmware of Lightning Detector, an experimental open
//  hardware project for early notification about approaching thunderstorm activity.
//  Copyright (C) 2024–2025 M. Frohne
//
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
////////////////////////////////////////////////////////////////////////////////////
*/

#include "as3935.h"
#include "auxil.h"
#include "buzzer.h"
#include "configuration.h"
#include "display.h"
#include "muxeddipswitch.h"
#include "pins.h"
#include "pushbutton.h"
#include "timercallback.h"
#include "vddmeasurement.h"

#include <USB/PluggableUSBSerial.h>

#include <nrf_nvic.h>
#include <nrf_soc.h>

#include <array>

//Function  declarations

void setupPowerSave();

void readConfiguration();

void tuneAntenna();

void detectLightnings();
bool processInterruptAS3935();

void isrAS3935();
void isrButtonClr();
void isrButtonDsp();
void isrWakeTimer();

//int main();
//void setup();
//void loop();

//Constants

constexpr size_t pushButtonBounceTime = 20;     //Debounce time for used push buttons in milliseconds

constexpr float buzzerFreq = 1000;              //Buzzer beep frequency in Hz
constexpr float buzzerDutyCycle = 0.1;          //Buzzer signal duty cycle

constexpr float buzzerLightBeepSecs = 0.2;      //Buzzer beep duration for lightning notification in seconds

constexpr size_t wakeTimerIntervalSecs = 120;   //Seconds of inactivity before forced wake-up via RTC (prevent missed AS3935 IRQ, etc.)

constexpr size_t vddMeasIntervalMins = 30;      //Scheduled interval between VDD measurements in minutes
constexpr size_t vddMeasSmallIntervalMins = 10; //Smaller VDD measurement interval in minutes for high lightning activity
constexpr float vddMeasLightRateThr = 2.;       //Number of lightnings per minute to switch to smaller measurement interval

constexpr size_t lightRateAvrgMins = 5;     //Minimum ('minimum' due to sleep) averaging time to determine current lightning activity/rate

constexpr float as3935MinVoltage = 2.4;     //Minimum allowed operating voltage for the AS3935 sensor chip in Volt
constexpr float systemMinVoltage = 2.4;     //Largest minimum allowed operating voltage for any system component in Volt
constexpr float systemIdleCurrent = 0.0041; //System current during VDD measurement (while awake and idle otherwise) in Ampere
constexpr float systemMaxCurrent = 0.0081;  //Maximum system current (e.g. during beep or display update) in Ampere
constexpr float batteryOCVoltage0 = 3.0;    //Open-circuit voltage of a nearly fresh coin cell (i.e. ~ nominal voltage) in Volt
constexpr float batteryIntResEOL = 55.0;    //Internal resistance of single coin cell around end of life (~systemMinVoltage) in Ohm
constexpr uint8_t systemBatteryCount = 2;   //Number of installed coin cells

//Minimum allowed voltage for VDD measurement from idle running system
constexpr float lowBatteryThrVoltage = systemMinVoltage + (batteryIntResEOL / systemBatteryCount) * (systemMaxCurrent - systemIdleCurrent);

//Interrupt flags

volatile bool irqWake = false;
volatile bool irqWakeAS3935 = false;
volatile bool irqWakeClr = false;
volatile bool irqWakeDsp = false;
volatile bool irqWakeTimer = false;

//External symbols

extern "C" { extern bool _us_ticker_initialized; }
const bool& timer1Used = _us_ticker_initialized;    //Determines if TIMER1 is used by mbed (see <mbed_wait_api.h>)

//Devices

Buzzer buzzer(Pins::Buzzer, buzzerFreq, buzzerDutyCycle);

PushButton buttonCLR(Pins::PushButtonClr, true, pushButtonBounceTime);
PushButton buttonDSP(Pins::PushButtonDsp, true, pushButtonBounceTime);

MuxedDIPSwitch<5, 5> dip({Pins::DIPSel1, Pins::DIPSel2, Pins::DIPSel3, Pins::DIPSel4, Pins::DIPSel5},
                         {Pins::DIPSens1, Pins::DIPSens2, Pins::DIPSens3, Pins::DIPSens4, Pins::DIPSens5});

AS3935 lDet(Pins::SPI_CS, Pins::IRQ);

#if USE_DISPLAY == USE_DISPLAY_WAVESHAREEPAPER154BW_SX1509IOEXPANDER
    constexpr uint8_t sx1509Addr = 0x3E;
    Display display(sx1509Addr, SX1509Pins::Display_CS, SX1509Pins::Display_DC, SX1509Pins::Display_RST, SX1509Pins::Display_BUSY);
#else
    Display display;
#endif

//"Virtual devices" (using internal periphery)

TimerCallback wakeTimer(8*wakeTimerIntervalSecs, &isrWakeTimer);    //Periodic wake-up timer (binds RTC interrupt)

//Other globals

Configuration config;

using Auxil::RunMode;
RunMode runMode = RunMode::Normal;

bool serialEnabled = false;

AS3935::InterruptType lDetLastInterrupt = AS3935::InterruptType::Lightning; //Last reported interrupt type from AS3935
uint32_t lDetLastEnergy = 0;                                                //Last reported lightning energy from AS3935 (raw value)
uint8_t lDetStormDist = AS3935::stormDistanceOutOfRange;                    //Last reported thunderstorm distance from AS3935 in km

//Function definitions

/*!
 * \brief Configure some power save settings.
 */
void setupPowerSave()
{
    //Turn off power LED
    digitalWrite(Pins::LED_Power, LOW);

    //Disable IMU
    digitalWrite(PIN_ENABLE_SENSORS_3V3, LOW);
    digitalWrite(PIN_ENABLE_I2C_PULLUP, LOW);

    //Configure pull-down for unused RX/TX pins
    pinMode(0, INPUT_PULLDOWN);
    pinMode(1, INPUT_PULLDOWN);

    //Disable UART

    NRF_UARTE0->TASKS_STOPTX = 1;
    NRF_UARTE0->TASKS_STOPRX = 1;
    NRF_UARTE0->ENABLE = 0;

    NRF_UARTE1->TASKS_STOPTX = 1;
    NRF_UARTE1->TASKS_STOPRX = 1;
    NRF_UARTE1->ENABLE = 0;

    NRF_UART0->TASKS_STOPTX = 1;
    NRF_UART0->TASKS_STOPRX = 1;
    NRF_UART0->ENABLE = 0;

    //Disable unused I2C peripheral(s)
    if (!useDisplay)
        NRF_TWI0->ENABLE = 0;
    NRF_TWI1->ENABLE = 0;

    //Disable two unused SPI peripherals
    NRF_SPI0->ENABLE = 0;
    NRF_SPI1->ENABLE = 0;

    //Ensure system is in low power mode
    NRF_POWER->TASKS_LOWPWR = 1;
}

/*!
 * \brief Read the DIP switch configuration bits for setting the AS3935 registers.
 */
void readConfiguration()
{
    std::array<bool, 25> conf25 = dip.readAllBits();
    std::array<bool, 24> conf;

    for (size_t i = 0; i < 24; ++i)
        conf[i] = conf25[i];

    config.load(conf);
}

/*!
 * \brief Perform manual AS3935 antenna tuning (endless loop).
 */
void tuneAntenna()
{
    while (true)
    {
        buttonDSP.waitPressed();

        readConfiguration();

        lDet.writeConfiguration(config);

        uint8_t lcoFDIV = config.getRegister(Configuration::RegIdent::LCO_FDIV);

        //If divided frequency is in audible range, output corresponding sound using buzzer; otherwise just wait for button release
        if (lcoFDIV == 0b11 || lcoFDIV == 0b10)
        {
            size_t tBuzzerOnDelay;
            if (lcoFDIV == 0b11)
                tBuzzerOnDelay = static_cast<size_t>(1000000./3906.25*buzzerDutyCycle);
            else
                tBuzzerOnDelay = static_cast<size_t>(1000000./7812.50*buzzerDutyCycle);

            while (buttonDSP.pressed())
            {
                while (!lDet.irqHigh())
                    ;

                buzzer.switchOutputOn();

                delayMicroseconds(tBuzzerOnDelay);  //Use normal beep duty cycle to improve sound

                buzzer.switchOutputOff();

                while (lDet.irqHigh())
                    ;
            }
        }
        buttonDSP.waitReleased();
    }
}

/*!
 * \brief Perform the lightning detection (endless loop).
 */
void detectLightnings()
{
    //Enable lightning notification via buzzer beep (will be disabled when supply voltage gets too low)
    bool beepEnabled = true;

    //Detected low battery voltage during occasional VDD measurement below
    bool lowBattery = false;

    //Count number of wake-ups from sleep
    size_t wakeUpCtr = 0;

    //Count number of detected lightnings
    size_t lightningCtr = 0;

    //Accumulate passed time during sleep when waking up to occasionally trigger a VDD measurement
    size_t sleepSecsSinceLastVDDMeas = 60*vddMeasIntervalMins;  //Do initial measurement at startup

    //Latest VDD measurement result
    float supplyVoltage = 0;

    //Successively calculate the average rate of current lightning activity
    size_t sleepSecsSinceLastRateAvrg = 0;  //Passed time during sleep since last rate average
    size_t lightsSinceLastRateAvrg = 0;     //Number of lightnings since last rate average
    float lightningRate = 0;                //Lightnings per minute

    //Accumulate estimated total run time
    size_t runTimeFullHours = 0;        //Full hours of run time (only updated from below seconds upon every display update)
    size_t runTimeRemainderSecs = 0;    //Accumulated seconds of run time (carried over to above hours upon every display update)
    size_t lightsSinceLastDisplay = 0;  //Number of lightnings since last display update

    //Define a common display update routine
    auto updateDisplay = [beepEnabled, &supplyVoltage, &lightningCtr, &lightningRate,
                          &runTimeFullHours, &runTimeRemainderSecs, &lightsSinceLastDisplay]() -> void
    {
        float batteryPercentage = Auxil::calcBatteryPercentage(supplyVoltage, batteryOCVoltage0, systemMinVoltage,
                                                               systemIdleCurrent, systemMaxCurrent, systemBatteryCount);

        if (batteryPercentage < 0.0)
            batteryPercentage = 0;
        else if (batteryPercentage > 100.0)
            batteryPercentage = 100.0;

        if (beepEnabled)
            runTimeRemainderSecs += static_cast<size_t>(buzzerLightBeepSecs*lightsSinceLastDisplay);

        lightsSinceLastDisplay = 0;

        if (runTimeRemainderSecs >= 3600)
        {
            size_t runTimeRemainderHours = runTimeRemainderSecs / 3600;

            runTimeFullHours += runTimeRemainderHours;
            runTimeRemainderSecs -= runTimeRemainderHours * 3600;
        }

        float runTimeHours = runTimeFullHours + (static_cast<float>(runTimeRemainderSecs) / 3600.);

        display.init();
        display.update(lightningCtr, lightningRate, lDetStormDist, batteryPercentage, supplyVoltage,
                       runTimeHours, runMode, serialEnabled, lDetLastInterrupt);
        display.sleep();
    };

    while (true)
    {
        //Indicate wake-up reason via short RGB LED flash
        if (irqWakeAS3935)
            digitalWrite(Pins::LED_RGB_R, LOW);
        if (irqWakeClr || irqWakeDsp)
            digitalWrite(Pins::LED_RGB_G, LOW);
        if (irqWakeTimer)
            digitalWrite(Pins::LED_RGB_B, LOW);

        //Debounce pressed buttons
        if (irqWakeClr)
            buttonCLR.waitPressed();
        if (irqWakeDsp)
            buttonDSP.waitPressed();

        //Wait and turn off LEDs again (see above)
        delay(10);
        digitalWrite(Pins::LED_RGB_R, HIGH);
        digitalWrite(Pins::LED_RGB_G, HIGH);
        digitalWrite(Pins::LED_RGB_B, HIGH);

        //Calculate average rate of current lightning activity

        size_t secsSinceLastRateAvrg = sleepSecsSinceLastRateAvrg;
        if (beepEnabled)
            secsSinceLastRateAvrg += static_cast<size_t>(buzzerLightBeepSecs*lightsSinceLastRateAvrg);

        if (secsSinceLastRateAvrg >= 60*lightRateAvrgMins)
        {
            float avMins = static_cast<float>(secsSinceLastRateAvrg) / 60.;

            lightningRate = static_cast<float>(lightsSinceLastRateAvrg) / avMins;

            sleepSecsSinceLastRateAvrg = 0;
            lightsSinceLastRateAvrg = 0;
        }

        //Occasionally measure VDD (every >~ N minutes and only if already awake); adjust interval with
        //lightning activity (i.e. current consumption); always measure on push button event (user interaction)
        if (irqWakeClr || irqWakeDsp || (sleepSecsSinceLastVDDMeas >= 60*vddMeasIntervalMins) ||
                ((lightningRate > vddMeasLightRateThr) && (sleepSecsSinceLastVDDMeas >= 60*vddMeasSmallIntervalMins)))
        {
            sleepSecsSinceLastVDDMeas = 0;

            //Wait for release of pressed buttons first in order to avoid the influence of the additional current on the measurement
            if (irqWakeClr)
                buttonCLR.waitReleased();
            if (irqWakeDsp)
                buttonDSP.waitReleased();

            //Let VDD settle a bit
            delay(50);

            supplyVoltage = VDDMeasurement::measureVoltage();

            if (serialEnabled)
            {
                Serial.print("VDD: ");
                Serial.print(supplyVoltage, 3);
                Serial.print(" V\n");
            }

            //Warn when voltage is expected to drop below minimum system operating voltage during buzzer beep; also disable beep then
            if (!lowBattery && (supplyVoltage < lowBatteryThrVoltage))
            {
                lowBattery = true;

                //Play warning sound
                for (size_t i = 0; i < 6; ++i)
                {
                    delay(400);
                    buzzer.beepSingle(0.2);
                    delay(150);
                    buzzer.beepSingle(0.05);
                }

                beepEnabled = false;

                //Automatically update display to also visually notify about low battery state
                updateDisplay();

                if (serialEnabled)
                {
                    Serial.print("Warning: Low battery! Measured VDD should be >~ ");
                    Serial.print(lowBatteryThrVoltage, 3);
                    Serial.print(" V! Disabling beep and display update.\n");
                }
            }

            //Check if low voltage is still sufficient to run AS3935; if not, finally stop operation, repeatedly show LED notifications
            if (lowBattery && (supplyVoltage < as3935MinVoltage))
            {
                bool emptyBattery = true;

                //Measure voltage 10 times in 10 seconds to be sure about empty battery state
                for (size_t i = 0; i < 10; ++i)
                {
                    delay(1000);
                    if (VDDMeasurement::measureVoltage() >= as3935MinVoltage)
                    {
                        emptyBattery = false;
                        break;
                    }
                }

                //Voltage too low to still run AS3935! Stop main loop and sleep, occasionally wake up to let LED blink for notification
                if (emptyBattery)
                {
                    if (serialEnabled)
                    {
                        Serial.print("Warning: Empty battery! Measured VDD is below minimum AS3935 operating voltage of ");
                        Serial.print(as3935MinVoltage, 3);
                        Serial.print(" V! Going to sleep...\n");

                        serialEnabled = false;

                        Serial.end();
                        NRF_USBD->ENABLE = 0;
                        while (NRF_USBD->ENABLE == 1)
                            ;
                    }

                    while (true)
                    {
                        irqWakeTimer = false;

                        wakeTimer.startTimer();

                        sd_nvic_DisableIRQ(RTC1_IRQn);
                        sd_nvic_ClearPendingIRQ(RTC1_IRQn);

                        __set_FPSCR(__get_FPSCR() & ~(0x9Fu));
                        (void) __get_FPSCR();
                        sd_nvic_ClearPendingIRQ(FPU_IRQn);

                        if (timer1Used)
                            NRF_TIMER1->TASKS_STOP = 1;

                        while (!irqWakeTimer)
                            sd_app_evt_wait();

                        if (timer1Used)
                            NRF_TIMER1->TASKS_START = 1;

                        sd_nvic_EnableIRQ(RTC1_IRQn);

                        wakeTimer.stopTimer();

                        for (size_t i = 0; i < 5; ++i)
                        {
                            delay(400);
                            digitalWrite(Pins::LED_RGB_B, LOW);
                            delay(350);
                            digitalWrite(Pins::LED_RGB_B, HIGH);
                        }
                    }
                }
            }
        }

        //If woke up from AS3935, process all AS3935 events; if woke up from button,
        //stay awake until button released and poll for new AS3935 interrupts in the meantime
        while (lDet.irqHigh() || (irqWakeClr && buttonCLR.pressed()) || (irqWakeDsp && buttonDSP.pressed()))
        {
            if (lDet.irqHigh())
            {
                digitalWrite(Pins::LED_RGB_R, LOW);
                bool lightning = processInterruptAS3935();
                digitalWrite(Pins::LED_RGB_R, HIGH);

                if (lightning)
                {
                    ++lightningCtr;
                    ++lightsSinceLastRateAvrg;
                    ++lightsSinceLastDisplay;

                    if (beepEnabled)
                        buzzer.beepSingle(buzzerLightBeepSecs);
                }
            }
        }

        //If requested, reset lightning statistics (in particular also AS3935 internal statistics) and rate measurement
        if (irqWakeClr)
        {
            //Clear AS3935 lightning statistics
            lDet.clearStatistics();

            //Reset latest interrupt type, lightning energy and storm distance received from AS3935
            lDetLastInterrupt = AS3935::InterruptType::Lightning;
            lDetLastEnergy = 0;
            lDetStormDist = AS3935::stormDistanceOutOfRange;

            //Reset lightning counter
            lightningCtr = 0;

            //Reset lightning rate measurement
            sleepSecsSinceLastRateAvrg = 0;
            lightsSinceLastRateAvrg = 0;
            lightningRate = 0;
        }

        //If requested, update display content (disable updating when battery voltage gets too low)
        if (irqWakeDsp)
        {
            if (!lowBattery)
                updateDisplay();
            else
            {
                //Let LED blink briefly to remember about display not updating due to low battery voltage
                for (size_t i = 0; i < 3; ++i)
                {
                    delay(130);
                    digitalWrite(Pins::LED_RGB_G, LOW);
                    delay(20);
                    digitalWrite(Pins::LED_RGB_G, HIGH);
                }
            }
        }

        //Debounce released buttons before attaching interrupts again
        if (irqWakeClr)
            buttonCLR.waitReleased();
        if (irqWakeDsp)
            buttonDSP.waitReleased();

        //Reset interrupt flags
        irqWake = false;
        irqWakeAS3935 = false;
        irqWakeClr = false;
        irqWakeDsp = false;
        irqWakeTimer = false;

        //Go to sleep

        wakeTimer.startTimer();

        lDet.enableInterrupt(isrAS3935);
        buttonCLR.enableInterrupt(isrButtonClr);
        buttonDSP.enableInterrupt(isrButtonDsp);

        sd_nvic_DisableIRQ(RTC1_IRQn);
        sd_nvic_ClearPendingIRQ(RTC1_IRQn);

        __set_FPSCR(__get_FPSCR() & ~(0x9Fu));
        (void) __get_FPSCR();
        sd_nvic_ClearPendingIRQ(FPU_IRQn);

        if (timer1Used)
            NRF_TIMER1->TASKS_STOP = 1;

        if (!lDet.irqHigh())
        {
            while (!irqWake)
                sd_app_evt_wait();

            ++wakeUpCtr;
        }

        //Wake up again

        if (timer1Used)
            NRF_TIMER1->TASKS_START = 1;

        sd_nvic_EnableIRQ(RTC1_IRQn);

        lDet.disableInterrupt();
        buttonCLR.disableInterrupt();
        buttonDSP.disableInterrupt();

        //Accumulate sleep time

        uint32_t timerTicksSinceLastWake = wakeTimer.stopTimer();

        size_t sleepSecs;

        if (irqWakeTimer)
            sleepSecs = wakeTimerIntervalSecs;  //Use fixed interval value here as timer interrupt already cleared counter
        else
            sleepSecs = static_cast<size_t>(static_cast<float>(timerTicksSinceLastWake) / 8.);

        sleepSecsSinceLastVDDMeas += sleepSecs;
        sleepSecsSinceLastRateAvrg += sleepSecs;

        runTimeRemainderSecs += sleepSecs;
    }
}
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
void loop()
{
    switch(runMode)
    {
        case RunMode::TuneAntenna:
        {
            tuneAntenna();
            break;
        }
        case RunMode::UnmaskDisturbers:
        case RunMode::Normal:
        default:
        {
            detectLightnings();
            break;
        }
    }
}

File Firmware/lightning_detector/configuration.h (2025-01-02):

/*
////////////////////////////////////////////////////////////////////////////////////
//
//  This file is part of the firmware of Lightning Detector, an experimental open
//  hardware project for early notification about approaching thunderstorm activity.
//  Copyright (C) 2024–2025 M. Frohne
//
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
////////////////////////////////////////////////////////////////////////////////////
*/

#ifndef CONFIGURATION_H
#define CONFIGURATION_H

#include <Arduino.h>

#include <array>

/*!
 * \brief Register configuration object for the AS3935 registers.
 *
 * Stores the configurable settings of the AS3935 sensor in the form of a series of register values.
 *
 * The raw configuration (see load() and getRawConfig()) has a length of 24 bits and must
 * have the following format (always starting with MSB, bit lengths in parentheses):
 *
 * {RegIdent::AFE_GB (5), RegIdent::NF_LEV (3), RegIdent::WDTH (4), RegIdent::SREJ (4),
 *  RegIdent::TUN_CAP (4), RegIdent::LCO_FDIV (2), RegIdent::MIN_NUM_LIGH (2)}
 */
class Configuration
{
public:
    enum class RegIdent : uint8_t;

public:
    Configuration();                            ///< Constructor.
    //
    void load(std::array<bool, 24> pRawConf);   ///< Load configuration from raw DIP switch positions.
    //
    uint8_t getRegister(RegIdent pReg) const;   ///< Extract a register value from loaded raw configuration.
    std::array<bool, 24> getRawConfig() const;  ///< Get loaded raw configuration bits.

private:
    std::array<bool, 24> conf;  ///< Raw DIP configuration bits (mapped to registers via 'regOfsLenMap').

public:
    /*!
     * \brief %AS3935 registers configurable via Configuration.
     */
    enum class RegIdent : uint8_t
    {
        AFE_GB = 0,       ///< Analog front-end gain (indoor/outdoor) [5 bits].
        NF_LEV = 1,       ///< Noise floor level [3 bits].
        WDTH = 2,         ///< Watchdog threshold [4 bits].
        SREJ = 3,         ///< Spike rejection level [4 bits].
        TUN_CAP = 4,      ///< Antenna capacitor tuning value [4 bits].
        LCO_FDIV = 5,     ///< Divsion ratio for antenna resonance on interrupt pin (tuning mode) [2 bits].
        MIN_NUM_LIGH = 6  ///< Minimum number of lightnings to trigger an interrupt [2 bits].
    };

private:
    static constexpr uint8_t regOfsLenMap[][3] = {{static_cast<uint8_t>(RegIdent::AFE_GB), 0, 5},
                                                  {static_cast<uint8_t>(RegIdent::NF_LEV), 5, 3},
                                                  {static_cast<uint8_t>(RegIdent::WDTH), 8, 4},
                                                  {static_cast<uint8_t>(RegIdent::SREJ), 12, 4},
                                                  {static_cast<uint8_t>(RegIdent::TUN_CAP), 16, 4},
                                                  {static_cast<uint8_t>(RegIdent::LCO_FDIV), 20, 2},
                                                  {static_cast<uint8_t>(RegIdent::MIN_NUM_LIGH), 22, 2}};   ///< \brief Maps the configurable
                                                                                                            ///  %AS3935 registers to their
                                                                                                            ///  lengths and their offsets
                                                                                                            ///  within the 'conf' array.
};

#endif // CONFIGURATION_H

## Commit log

2024-04-07 Initial commit.
    Add Lightning Detector 0.5.0.
    [arduino_nano_33_ble.kicad_pcb, configuration.h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]
2025-01-01 Add example STEP and STL files for a 3D printed case.
    [lightning_detector_case_bottom.step, lightning_detector_case_bottom.stl, lightning_detector_case_top.step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]
2025-01-01 Use smaller lightning rate threshold for switching to smaller VDD measurement interval.
2025-01-01 Update design files to KiCad version 8 and fix footprint overlap.
    [arduino_nano_33_ble.kicad_pcb, lightning_detector.kicad_pcb, lightning_detector.kicad_sch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]
2025-01-01 Update Gerber files.
    [lightning_detector-B_Cu.gbr, lightning_detector-B_Mask.gbr, lightning_detector-B_Paste.gbr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]
2025-01-01 Update schematics.
2025-01-01 Add pictures of 3D printed case assembly.
2025-01-02 Update copyright years.
    [configuration.h, lightning_detector.kicad_pcb, lightning_detector.kicad_sch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]

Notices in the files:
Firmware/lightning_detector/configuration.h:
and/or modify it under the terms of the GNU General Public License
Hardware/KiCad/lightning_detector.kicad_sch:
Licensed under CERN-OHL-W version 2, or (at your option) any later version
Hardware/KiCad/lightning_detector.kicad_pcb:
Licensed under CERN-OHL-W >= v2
